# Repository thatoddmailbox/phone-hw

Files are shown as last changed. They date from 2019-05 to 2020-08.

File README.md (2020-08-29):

# phone-hw
The hardware (schematic, PCB, Gerbers) portion of a [phone I built](https://github.com/thatoddmailbox/phone). You might also want to see [the firmware](https://github.com/thatoddmailbox/phone-fw).

Uses an Espressif ESP32-WROVER module as main CPU + WiFi/Bluetooth, a Quectel M26 modem for GSM and GPRS data, and a Quectel L80 module for GPS.

If you're curious, a [PDF schematic](./mfg/phone-hw.pdf) is available.

## Things that would be nice in a future version
Also see the [issues page](https://github.com/thatoddmailbox/phone-hw/issues) for more specific bugs with the latest revision.
* Figure out a different input method, since the current switch is EOL by the manufacturer. The ESP32 probably won't be able to run a full touchscreen interface smoothly, but switches like the one currently used are not very popular...
* Using a different module for GPS since the L80 has a built-in antenna that is the main contributor to the phone's thickness.
* Upgrading the modem to something that can do a bit more than 2G, though this might require a different communication mechanism than a simple UART
* Built-in speakers and microphone instead of requiring a Bluetooth headset
* 3.5mm headphone/headset jack - would require an external I2S DAC/ADC for best performance?
* CPU upgrade? The ESP32 is definitely powerful enough (for now...), but it's short on pins, which is why certain features had to be cut. Maybe ditch the extra 4MB SRAM and use those pins? (the extra RAM is currently unused by the firmware) However, it would also be nice to get a chip that could do USB host and/or device, especially if a future modem wants a USB connection
* USB-PD charging?? Probably not realistic, since it would require a battery that could safely handle the higher currents

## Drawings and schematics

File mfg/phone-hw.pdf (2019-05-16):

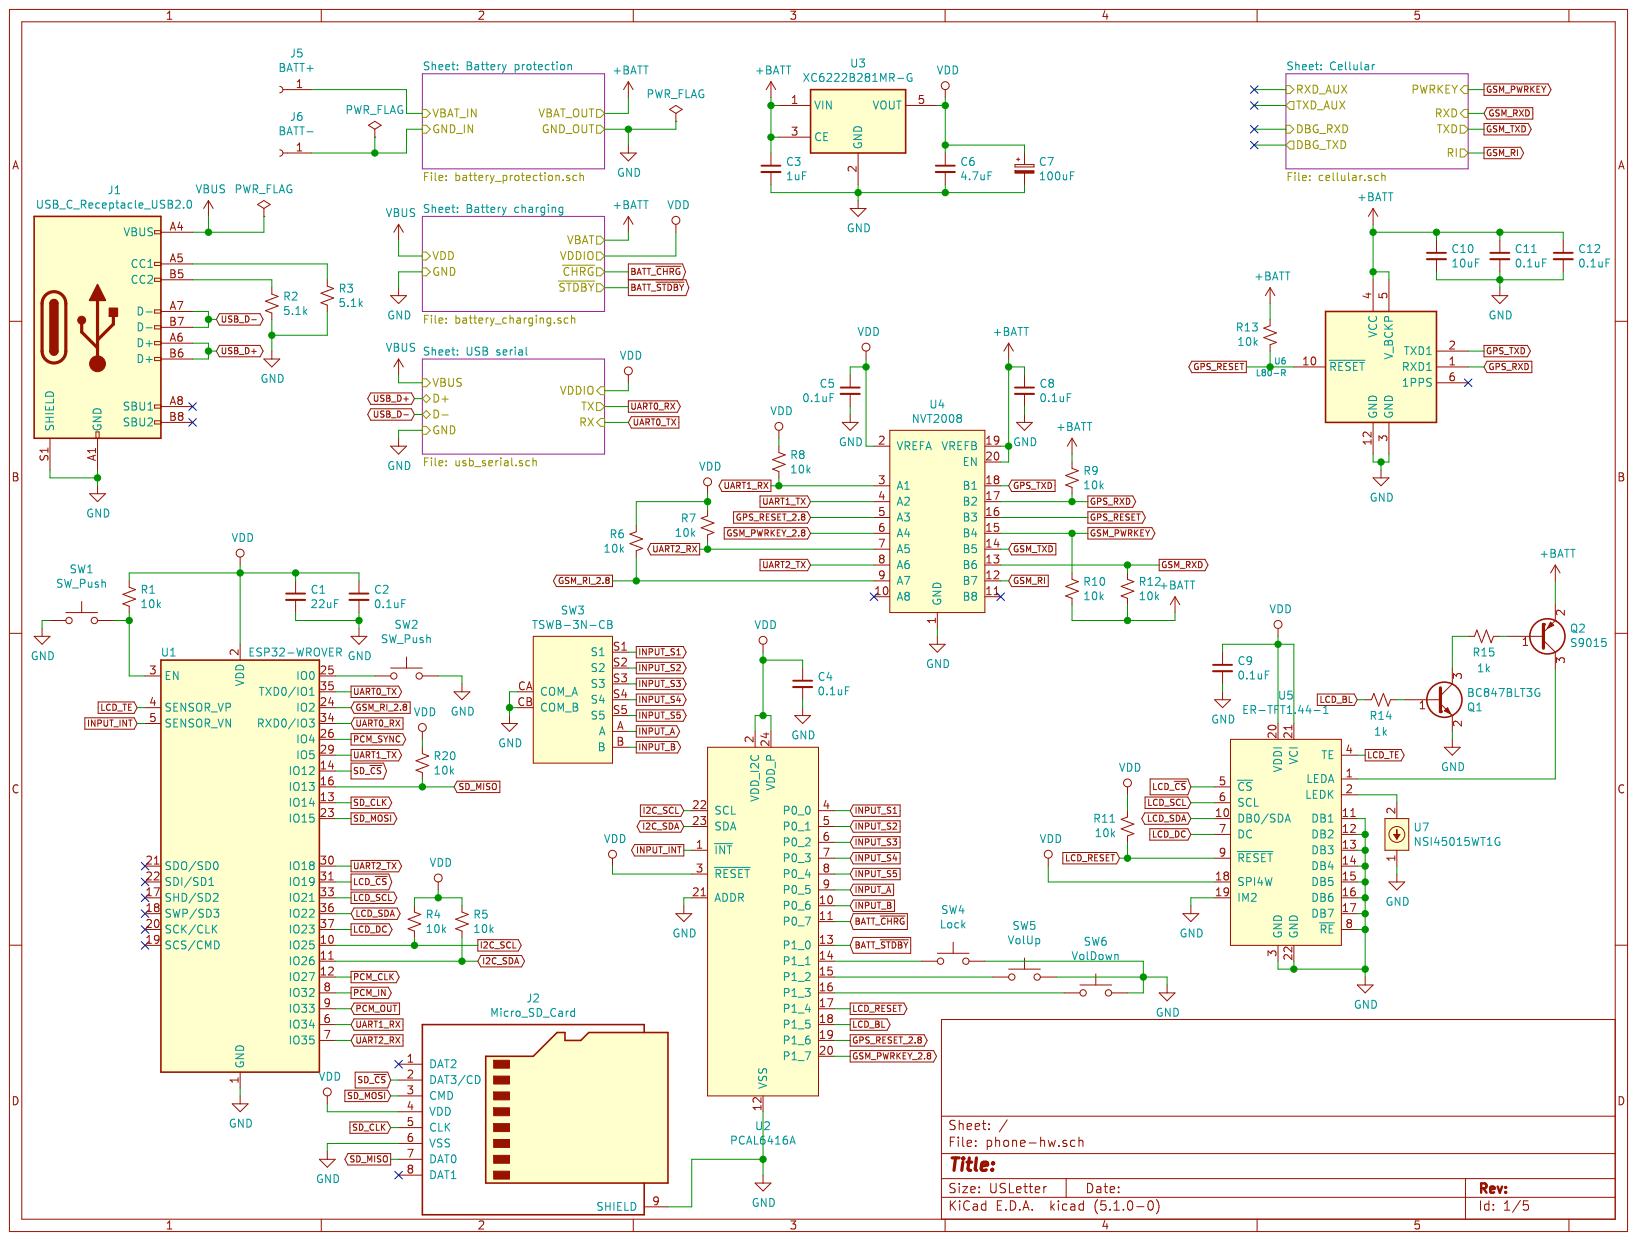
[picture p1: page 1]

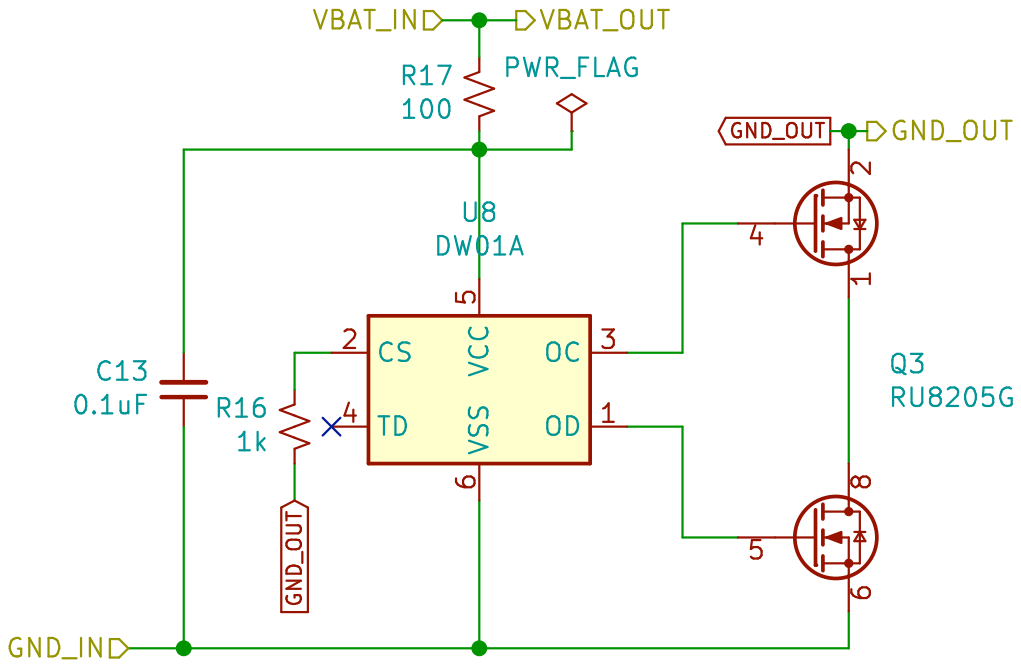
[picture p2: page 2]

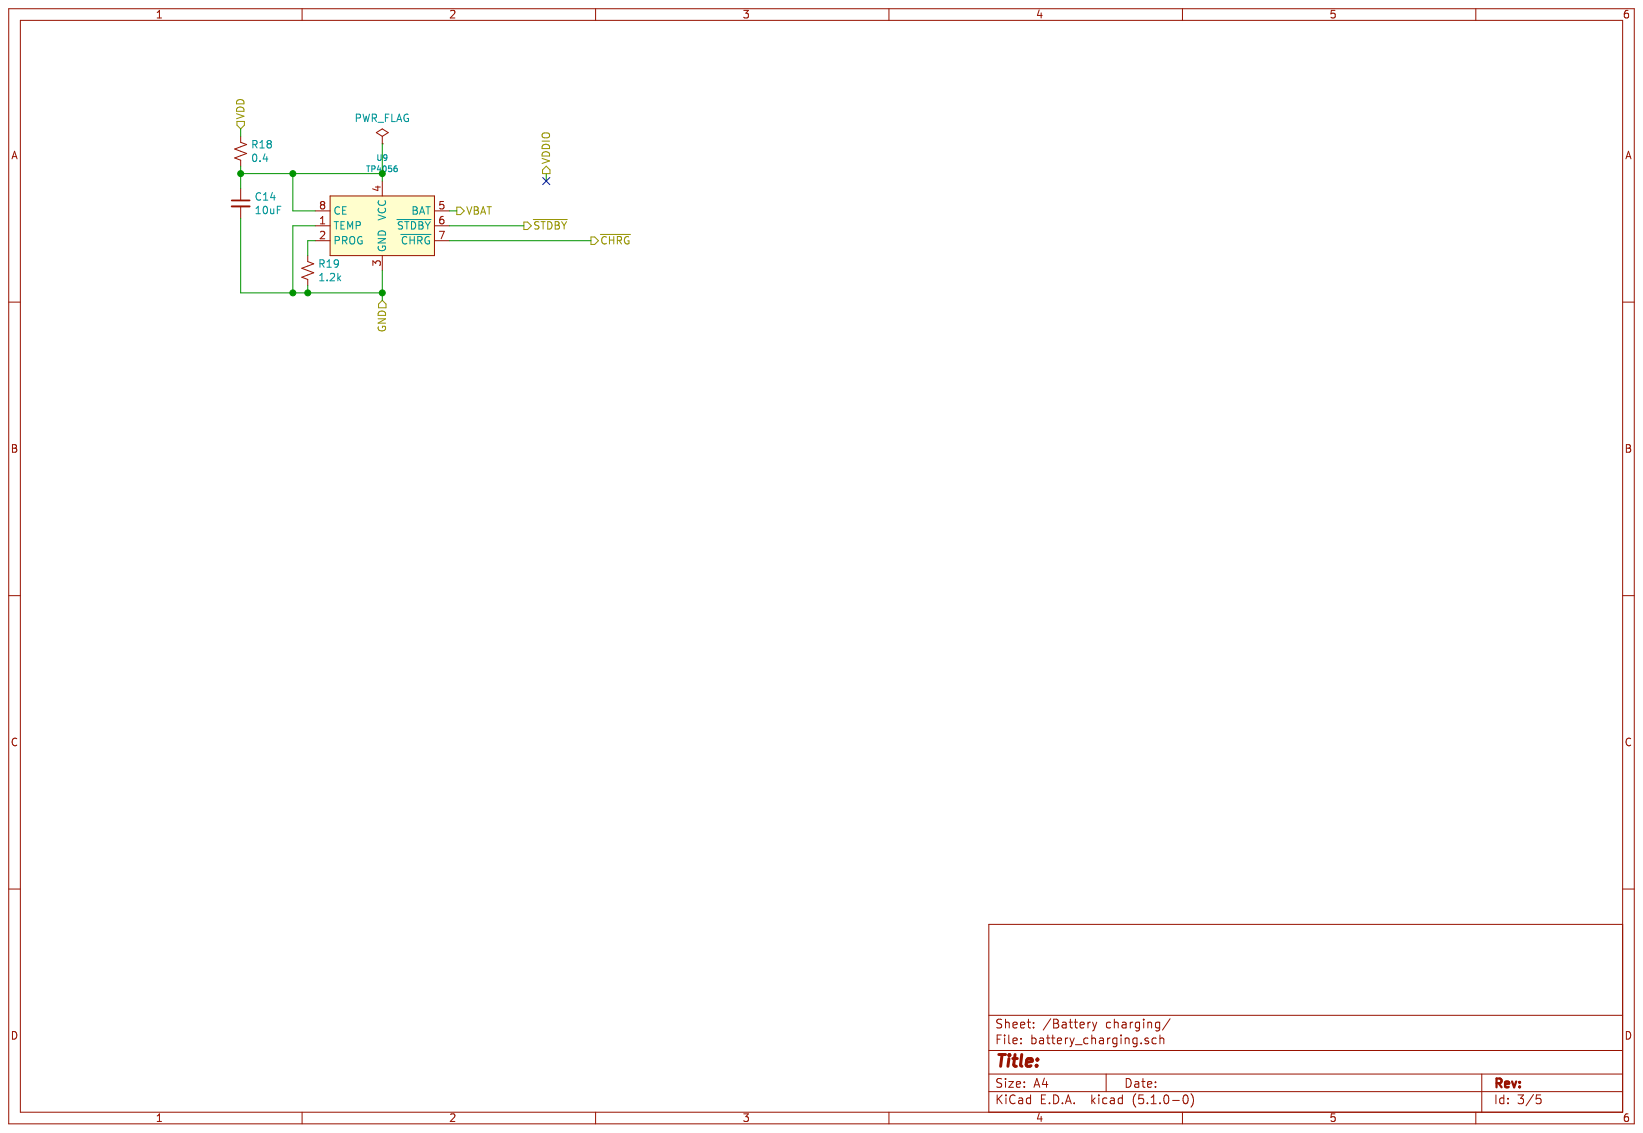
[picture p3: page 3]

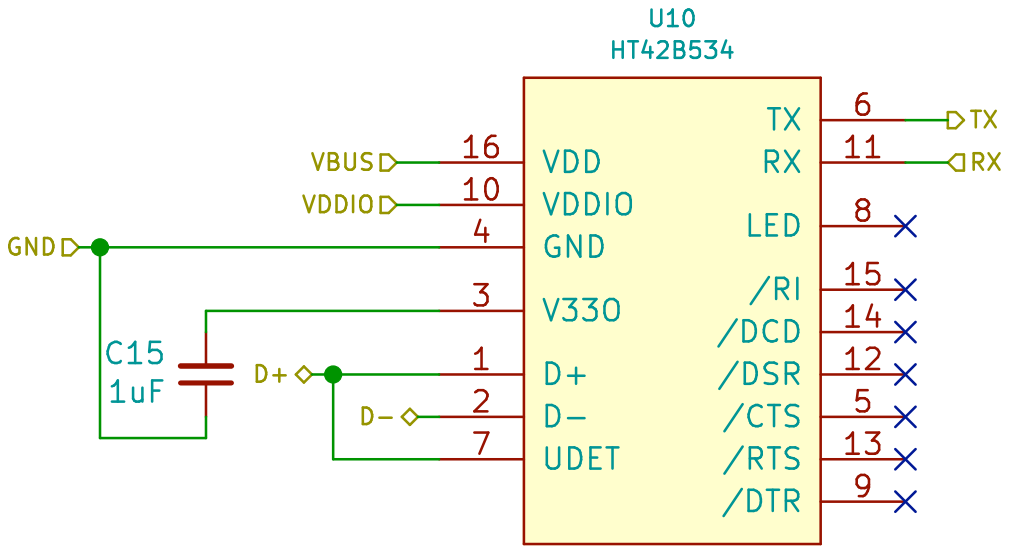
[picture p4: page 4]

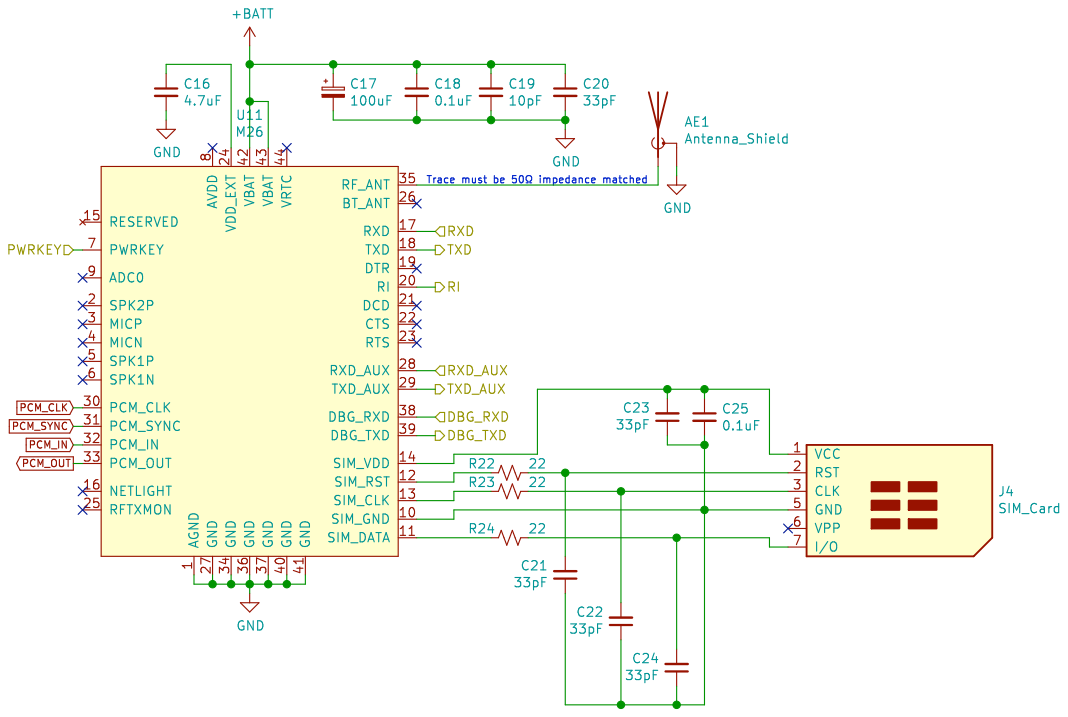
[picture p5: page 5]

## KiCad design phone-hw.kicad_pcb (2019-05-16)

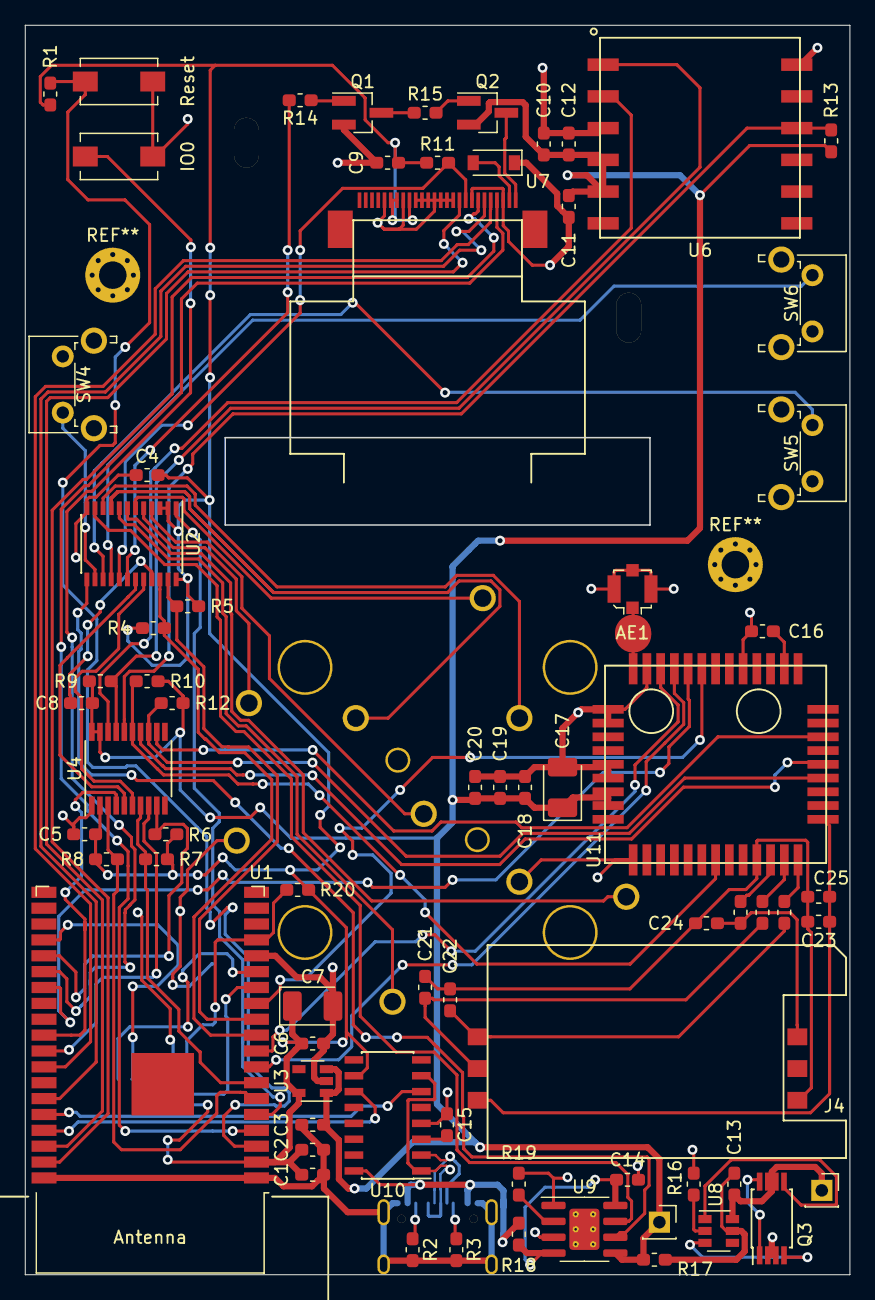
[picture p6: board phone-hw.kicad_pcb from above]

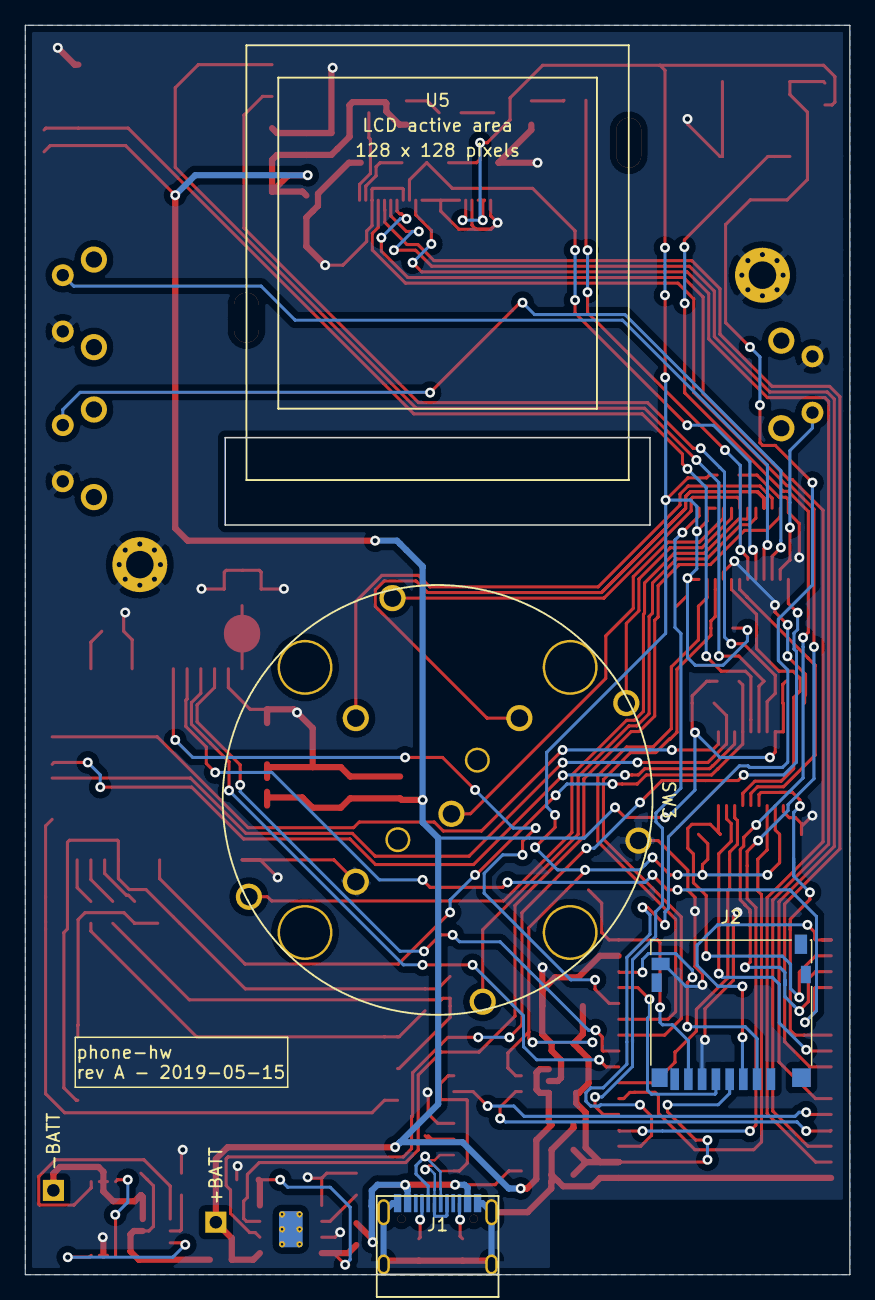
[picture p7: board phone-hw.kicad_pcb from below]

Board: 2 copper layers, 66.0 x 100.0 mm, 74 parts (4 on the bottom side), 80 nets.

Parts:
AE1: Antenna_Shield; U.FL_Molex_MCRF_73412-0110_Vertical
C1: 22uF; C_0603_1608Metric_Pad1.05x0.95mm_HandSolder
C2, C4, C5, C8, C9, C11, C12, C13, C18, C25: 0.1uF; C_0603_1608Metric_Pad1.05x0.95mm_HandSolder
C3, C15: 1uF; C_0603_1608Metric_Pad1.05x0.95mm_HandSolder
C6, C16: 4.7uF; C_0603_1608Metric_Pad1.05x0.95mm_HandSolder
C7, C17: 100uF; CP_EIA-3528-15_AVX-H_Pad1.50x2.35mm_HandSolder
C10, C14: 10uF; C_0603_1608Metric_Pad1.05x0.95mm_HandSolder
C19: 10pF; C_0603_1608Metric_Pad1.05x0.95mm_HandSolder
C20, C21, C22, C23, C24: 33pF; C_0603_1608Metric_Pad1.05x0.95mm_HandSolder
J1: USB_C_Receptacle_USB2.0; U262-16XN-4BVC11
J2: Micro_SD_Card; microSD_HC_Hirose_DM3D-SF
J4: SIM_Card; 7112S0815X19LF
J5: BATT+; PinSocket_1x01_P2.54mm_Vertical
J6: BATT-; PinSocket_1x01_P2.54mm_Vertical
Q1: BC847BLT3G; SOT-23_Handsoldering
Q2: S9015; SOT-23_Handsoldering
Q3: RU8205G; TSSOP-8_4.4x3mm_P0.65mm
R1, R4, R5, R6, R7, R8, R9, R10, R11, R12, R13, R20: 10k; R_0603_1608Metric_Pad1.05x0.95mm_HandSolder
R2, R3: 5.1k; R_0603_1608Metric_Pad1.05x0.95mm_HandSolder
R14, R15, R16: 1k; R_0603_1608Metric_Pad1.05x0.95mm_HandSolder
R17: 100; R_0603_1608Metric_Pad1.05x0.95mm_HandSolder
R18: 0.4; R_0603_1608Metric_Pad1.05x0.95mm_HandSolder
R19: 1.2k; R_0603_1608Metric_Pad1.05x0.95mm_HandSolder
R22, R23, R24: 22; R_0603_1608Metric_Pad1.05x0.95mm_HandSolder
SW1, SW2: SW_Push; SW_SPST_EVQPE1
SW3: TSWB-3N-CB
SW4: Lock; SW_Tactile_SPST_Angled_PTS645Vx58-2LFS
SW5: VolUp; SW_Tactile_SPST_Angled_PTS645Vx58-2LFS
SW6: VolDown; SW_Tactile_SPST_Angled_PTS645Vx58-2LFS
U1: ESP32-WROVER
U2: PCAL6416A; TSSOP-24_4.4x7.8mm_P0.65mm
U3: XC6222B281MR-G; SOT-23-5
U4: NVT2008; TSSOP-20_4.4x6.5mm_P0.65mm
U5: ER-TFT1.44-1; ER-TFT1.44-1-FOLD
U6: L80-R
U7: NSI45015WT1G; D_SOD-123
U8: DW01A; SOT-23-6
U9: TP4056; SOIC-8-1EP_3.9x4.9mm_P1.27mm_EP2.41x3.3mm_ThermalVias
U10: HT42B534; SOIC-16_3.9x9.9mm_P1.27mm
U11: M26

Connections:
+BATT: C3.1, C8.1, C10.1, C11.1, C12.1, C17.1, C18.1, C19.1, C20.1, J5.1, Q2.2, R9.1, R10.2, R12.2, R13.2, R17.2, U3.1, U3.3, U4.19, U4.20, U6.4, U6.5, U9.5, U11.42, U11.43
/Battery protection/GND_IN: C13.1, J6.1, Q3.6, Q3.7, U8.6
BATT_~CHRG: U2.11, U9.7
BATT_~STDBY: U2.13, U9.6
GND_OUT: AE1.2, C1.2, C2.2, C3.2, C4.2, C5.2, C6.2, C7.2, C8.2, C9.2, C10.2, C11.2, C12.2, C14.2, C15.1, C16.2, C17.2, C18.2, C19.2, C20.2, J1.A1, J1.B1, J1.S1, J2.6, J2.9, Q1.2, Q3.2, Q3.3, R2.2, R3.2, R16.1, R19.2, SW1.2, SW2.2, SW3.CA, SW3.CB, SW4.2, SW5.2, SW6.2, U1.1, U1.15, U1.38, U2.12, U2.21, U3.2, U4.1, U5.3, U5.8, U5.11, U5.12, U5.13, U5.14, U5.15, U5.16, U5.17, U5.19, U5.22, U6.3, U6.12, U7.1, U9.1, U9.3, U10.4, U11.1, U11.27, U11.34, U11.36, U11.37, U11.40, U11.41
GPS_RESET: R13.1, U4.16, U6.10
GPS_RESET_2.8: U2.19, U4.5
GPS_RXD: R9.2, U4.17, U6.1
GPS_TXD: U4.18, U6.2
GSM_PWRKEY: R10.1, U4.15, U11.7
GSM_PWRKEY_2.8: U2.20, U4.6
GSM_RI: U4.12, U11.20
GSM_RI_2.8: R6.2, U1.24, U4.9
GSM_RXD: R12.1, U4.13, U11.17
GSM_TXD: U4.14, U11.18
I2C_SCL: R4.2, U1.10, U2.22
I2C_SDA: R5.2, U1.11, U2.23
INPUT_A: SW3.A, U2.9
INPUT_B: SW3.B, U2.10
INPUT_INT: U1.5, U2.1
INPUT_S1: SW3.S1, U2.4
INPUT_S2: SW3.S2, U2.5
INPUT_S3: SW3.S3, U2.6
INPUT_S4: SW3.S4, U2.7
INPUT_S5: SW3.S5, U2.8
LCD_BL: R14.2, U2.18
LCD_DC: U1.37, U5.7
LCD_RESET: R11.1, U2.17, U5.9
LCD_SCL: U1.33, U5.6
LCD_SDA: U1.36, U5.10
LCD_TE: U1.4, U5.4
LCD_~CS: U1.31, U5.5
unnamed: AE1.1, U11.35
unnamed: C13.2, R17.1, U8.5
unnamed: C14.1, R18.2, U9.4, U9.8
unnamed: C15.2, U10.3
unnamed: C16.1, U11.24
unnamed: C21.1, C22.1, C23.1, C24.1, C25.2, J4.5, U11.10
unnamed: C21.2, J4.2, R22.1
unnamed: C22.2, J4.3, R23.1
unnamed: C23.2, C25.1, J4.1, U11.14
unnamed: C24.2, J4.7, R24.1
unnamed: J1.A5, R3.1
unnamed: J1.B5, R2.1
unnamed: Q1.1, R14.1
unnamed: Q1.3, R15.2
unnamed: Q2.1, R15.1
unnamed: Q2.3, U5.1
unnamed: Q3.1, Q3.8
unnamed: Q3.4, U8.3
unnamed: Q3.5, U8.1
unnamed: R1.2, SW1.1, U1.3
unnamed: R16.2, U8.2
unnamed: R19.1, U9.2
unnamed: R22.2, U11.12
unnamed: R23.2, U11.13
unnamed: R24.2, U11.11
unnamed: SW2.1, U1.25
unnamed: SW4.1, U2.14
unnamed: SW5.1, U2.15
unnamed: SW6.1, U2.16
unnamed: U5.2, U7.2
PCM_CLK: U1.12, U11.30
PCM_IN: U1.8, U11.32
PCM_OUT: U1.9, U11.33
PCM_SYNC: U1.26, U11.31
SD_CLK: J2.5, U1.13
SD_MISO: J2.7, R20.2, U1.16
SD_MOSI: J2.3, U1.23
SD_~CS: J2.2, U1.14
UART0_RX: U1.34, U10.6
UART0_TX: U1.35, U10.11
UART1_RX: R8.2, U1.6, U4.3
UART1_TX: U1.29, U4.4
UART2_RX: R7.2, U1.7, U4.7
UART2_TX: U1.30, U4.8
USB_D+: J1.A6, J1.B6, U10.1, U10.7
USB_D-: J1.A7, J1.B7, U10.2
VBUS: J1.A4, J1.B4, R18.1, U10.16
VDD: C1.1, C2.1, C4.1, C5.1, C6.1, C7.1, C9.1, J2.4, R1.1, R4.1, R5.1, R6.1, R7.1, R8.1, R11.2, R20.1, U1.2, U2.2, U2.3, U2.24, U3.5, U4.2, U5.18, U5.20, U5.21, U10.10

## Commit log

2019-05-14 commit current eval board schematic
    [battery_charging.sch, battery_protection.sch, cellular.sch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]
2019-05-14 fix label directions for some signals
    [phone-hw.sch]
2019-05-14 add some extra capacitance to the 2.8v line
    [phone-hw.sch]
2019-05-14 clear existing annotations from schematic
    [battery_charging.sch, battery_protection.sch, cellular.sch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]
2019-05-14 fix battery status line to be pulled up to 2.8v, not +vbat
    [battery_charging.sch, phone-hw.sch]
2019-05-14 fix lcd backlight circuit to use +batt instead of 2.8v for the backlight
    [phone-hw.sch]
2019-05-14 upgrade charge circuit to use tp4056, allowing the battery to charge faster without the charger throttling itself
    [battery_charging.sch, phone-hw.sch]
2019-05-14 increase size of pads on sim card connector
2019-05-14 add holes for bumps on back of tft scren
2019-05-14 add folded footprint of tft lcd
2019-05-14 set schematic to use folded display
    [phone-hw.sch]
2019-05-14 switch i/o expander to larger version, moving signals off esp32
    [phone-hw.sch]
2019-05-14 add buttons and connect pcm interface of modem to esp32
    [cellular.sch, phone-hw.sch]
2019-05-14 connect RI to esp32
    [cellular.sch, phone-hw.sch]
2019-05-14 fix pin type of BAT pin on tp4056
2019-05-15 annotate schematic and tweak some footprint associations
    [battery_charging.sch, battery_protection.sch, cellular.sch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]
2019-05-15 battery charger status lines don't need pullups, as they're built-in to i/o expander
    [battery_charging.sch]
2019-05-15 change battery to use two different connectors instead of a small pin header
    [phone-hw.sch]
2019-05-15 remove debug port for modem
    [phone-hw.sch]
2019-05-15 tweak some footprint associations
    [phone-hw.sch]
2019-05-15 start pcb with placed components
    [phone-hw.kicad_pcb]
2019-05-15 remove jtag port and move some other things around
    [phone-hw.sch]
2019-05-16 add sd card to schematic
    [phone-hw.sch]
2019-05-16 route pcb
    [phone-hw.kicad_pcb]
2019-05-16 add mounting holes
    [phone-hw.kicad_pcb]
2019-05-16 move mounting holes
    [phone-hw.kicad_pcb]
2019-05-16 add silkscreen info and battery indicators
    [phone-hw.kicad_pcb]
2019-05-16 add names of buttons to silkscreen
    [phone-hw.kicad_pcb]
2019-05-16 connect mounting holes to ground
    [phone-hw.kicad_pcb]
2019-05-16 add gerbers
    [phone-hw-B_Cu.gbr, phone-hw-B_Mask.gbr, phone-hw-B_SilkS.gbr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]
